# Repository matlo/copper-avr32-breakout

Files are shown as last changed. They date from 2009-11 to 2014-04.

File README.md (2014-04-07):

# AVR32 Breakout "Copper"

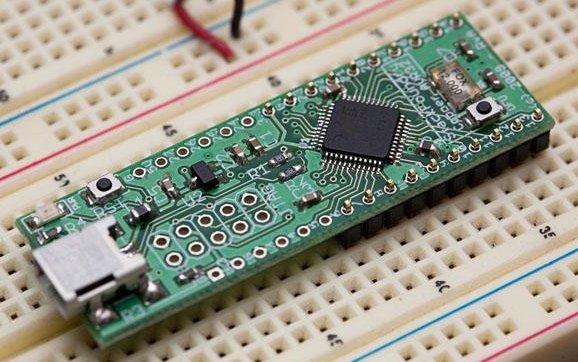
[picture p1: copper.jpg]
product


A breakout board for the AVR32 UC3B series of
processors. Specifically, the UC3B1256, a 48 pin part with 256KiB of
Flash (http://www.atmel.com/devices/AT32UC3B1256.aspx).

The year was 2009, and the Cortex-M3 was just a glimmer on some
product roadmaps. Yet Atmel delivered a 32-bit micro-controller which
was really efficient, had good performance, and was easy to use.

Modern designs should use a well-supported Cortex-M series part (M3,
M4, M0)

# Features

 * AVR 32 UC3B156
 * Mini-B USB connector
 * Breadboard-compatible pin pitch
 * All pins (except USB) broken out to the headers
 * JTAG connector
 * Reset button
 * Green LED :-)

# License

Creative Commons 3.0 Share-Alike Unported

# Design Status

This design was in larger (100-unit lots) production and was sold as a
pre-assembled kit.

## Boards available

A limited number of boards are available. Send an e-mail to
yann@stackfoundry.com with your mailing address. US postage is free,
International will be dealt with as it happens :-)

Boards will be populated with processors if they are available.

# Files available

The original design is available as Eagle 6.x (XML-based) design
files, in the eagle/ directory.

Gerber files from the Eagle board file are made available in the
gerber/ directory.

Schematic PDF is available in the root of this repository.

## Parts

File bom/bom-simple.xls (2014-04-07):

Qty | RefDeg | Manuf | Part# | Desc
1 | U1 | Atmel | AT32UC3B1256 | Microcontroller (MCU) 32-bit
2 | DFU,RST | Omrom | B3U-1000P | Tactile & Jog Switches Top Actuated w/o boss w/o ground
1 | U2 | Microchip | MCP1702 | Low Dropout (LDO) Regulators LDO w/ Low Quiescent
1 | Q1 | Fox | FQ5032B-12 | Crystals 12.0MHz 30ppm 0C +70C
2 | R1,R2 | Yageo | RC0603FR-0739RL | Resistor 0603 39ohm
1 | C4 | MuRata | GRM188F51A225ZE01D | Multilayer Ceramic Capacitors (MLCC) - SMD/SMT 0603 2.2uF 10volts Y5V +80-20%
1 | C1 | MuRata | GRM188F51A475ZE20D | Multilayer Ceramic Capacitors (MLCC) - SMD/SMT 0603 4.7uF 10volts Y5V +80-20%
1 | X2 | Hirose | UX60-MB-5ST | USB Mini B Conector
3 | C2,C5,C8,C3 | Panasonic | ECJ-1VB1C104K | CAP .1UF 16V CERAMIC X7R 0603
1 | R4 | Yageo | RC0603JR-07220RL | Resistors 0603 220 OHM 5%
2 | C7,C6 | MuRata | GRM1885C2A120JA01D | Multilayer Ceramic Capacitors (MLCC) - 0603 12pF or 16pF C0G/NPO
1 | L1 | Vishay | ILSB0805ERR10K | Common Mode Inductors .1uH 10%
1 | R3 | Yageo | RC0603JR-0747KL | Resistors 0603 47K OHM 5%
1 | PWR | Lumex | SML-LX1206GC-TR | LED 565NM WTR CLR GREEN 1206 SMD

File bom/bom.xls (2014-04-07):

Qty | RefDeg | Manuf | Part# | Desc | DigiKey Part# | Mouser Part#
1 | U3 | Atmel | AT32UC3B1256 | Microcontrollers (MCU) 32-bit |  | 556-AT32UC3B1256-AUT
2 |  | Omrom | B3U-1000P | Tactile & Jog Switches Top Actuated w/o boss w/o ground |  | 653-B3U-1000P
1 |  | Microchip | MCP1702 | Low Dropout (LDO) Regulators LDO w/ Low Quiescent |  | 579-MCP1702T3302E/CB
1 |  | Fox | FQ5032B-12 | Crystals 12.0MHz 30ppm 0C +70C |  | 559-FQ5032B-12
2 |  | Yageo | RC0603FR-0739RL | 0603 39ohm |  | 603-RC0603FR-0739RL
1 |  | MuRata | GRM188F51A225ZE01D | Multilayer Ceramic Capacitors (MLCC) - SMD/SMT 0603 2.2uF 10volts Y5V +80-20% |  | 81-GRM188F51A225ZE01
1 |  | MuRata | GRM188F51A475ZE20D | Multilayer Ceramic Capacitors (MLCC) - SMD/SMT 0603 4.7uF 10volts Y5V +80-20% |  | 81-GRM188F51A475ZE20
1 |  | FCI | 67997-420HLF | Headers 20 POS HEADER |  | 649-67997-420HLF | Optional
1 |  | Hirose | UX60-MB-5ST | USB Mini B |  | 798-ux60-mb-5st
3 |  | Panasonic | ECJ-1VB1C104K | CAP .1UF 16V CERAMIC X7R 0603 | PCC1762TR-ND
1 |  | Yageo | RC0603JR-07220RL | Thick Film Resistors SMD 220 OHM 5% |  | 603-RC0603JR-07220RL
2 |  | MuRata | GRM1885C2A120JA01D | Multilayer Ceramic Capacitors (MLCC) - SMD/SMT 0603 12pF 100volts C0G 5% |  | 81-GRM185C2A120JA01D
1 |  | Vishay | ILSB0805ERR10K | Common Mode Inductors .1uH 10% |  | 70-ILSB0805ERR10K
1 |  | Yageo | RC0603JR-0747KL | Thick Film Resistors SMD 47K OHM 5% |  | 603-RC0603JR-0747KL
1 | LED1 | Lumex | SML-LX1206GC-TR | LED 565NM WTR CLR GREEN 1206 SMD | 67-1357-1-ND
2 |  | FCI | 68000-216HLF | CONN HEADER 16POS .100 STR 15AU | 609-3260-ND |  | Optional

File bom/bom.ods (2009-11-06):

Qty | RefDeg | Manuf | Part# | Desc | DigiKey Part# | SFPN | Pricing
 |  |  |  |  |  |  | 1 | 10 | 25 | 100 | 1000 | Extended @ 100
1 | U3 | Atmel | AT32UC3B1256 | Microcontrollers (MCU) 32-bit | 556-AT32UC3B1256-AUT |  | 8.170000 | 8.060000 | 6.190000 | 5.700000 |  | 5.700000
2 |  | Omrom | B3U-1000P | Tactile & Jog Switches Top Actuated w/o boss w/o ground | 653-B3U-1000P |  | 0.770000 |  | 0.680000 | 0.580000 |  | 1.160000
1 |  | Microchip | MCP1702 | Low Dropout (LDO) Regulators LDO w/ Low Quiescent | 579-MCP1702T1802E/CB |  | 0.520000 | 0.480000 | 0.400000 | 0.360000 |  | 0.360000
1 |  | Fox | FQ5032B-12 | Crystals 12.0MHz 30ppm 0C +70C | 559-FQ5032B-12 |  | 1.070000 | 0.870000 | 0.780000 |  |  | 0.000000
2 |  | Yageo | RC0603FR-0739RL | 0603 39ohm | 603-RC0603FR-0739RL |  |  |  |  | 0.000100 |  | 0.000200
1 |  | MuRata | GRM188F51A225ZE01D | Multilayer Ceramic Capacitors (MLCC) - SMD/SMT 0603 2.2uF 10volts Y5V +80-20% | 81-GRM188F51A225ZE01 |  |  |  |  | 0.150000 |  | 0.150000
1 |  | MuRata | GRM188F51A475ZE20D | Multilayer Ceramic Capacitors (MLCC) - SMD/SMT 0603 4.7uF 10volts Y5V +80-20% | 81-GRM188F51A475ZE20 |  | 0.480000 |  |  | 0.150000 |  | 0.150000
1 |  | FCI | 67997-420HLF | Headers 20 POS HEADER | 649-67997-420HLF |  |  |  |  | 0.440000 |  | 0.440000
1 |  | Hirose | UX60-MB-5ST | USB Mini B | 798-ux60-mb-5st |  | 1.180000 |  |  | 0.700000 |  | 0.700000
 |  |  |  |  |  |  |  |  |  |  |  | 0.000000
 |  |  |  |  |  |  |  |  |  |  |  | 0.000000
 |  |  |  |  |  |  |  |  |  |  |  | 0.000000
 |  |  |  |  |  |  |  |  |  |  |  | 0.000000
 |  |  |  |  |  |  |  |  |  |  |  | 0.000000
1 | LED1,LED2 | Lumex | SML-LX1206GC-TR | LED 565NM WTR CLR GREEN 1206 SMD | 67-1357-1-ND | SFCLED-GRN-1206 | 0.160000 | 0.140000 | 0.140000 | 0.120000 |  | 0.120000
 |  |  |  |  |  |  |  |  |  |  |  |  | UpFront
 |  |  |  |  |  |  |  |  |  |  | Comp Total | 8.78
 |  |  |  |  |  |  |  |  |  |  | Box | 3
 |  |  |  |  |  |  |  |  |  |  | PCB | 3
 |  |  |  |  |  |  |  |  |  |  | Subtotal | 14.78 | 147.8
 |  |  |  |  |  |  |  |  |  |  | Margin | 29.56

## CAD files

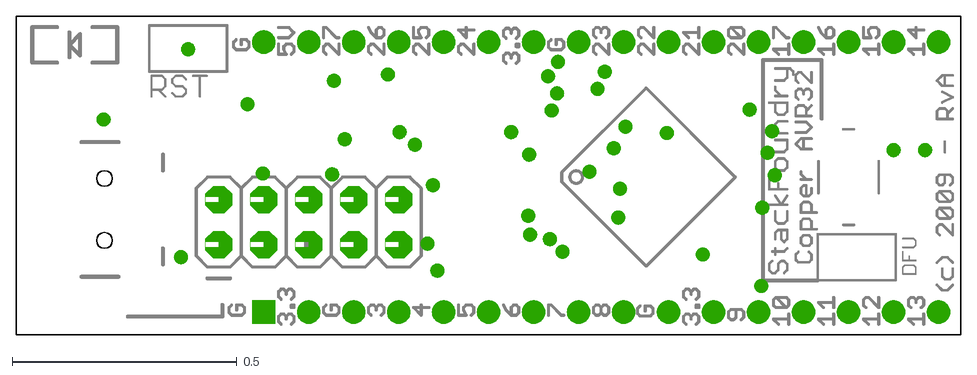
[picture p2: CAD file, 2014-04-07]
gerber/copper.dxf
2.10 x 0.707

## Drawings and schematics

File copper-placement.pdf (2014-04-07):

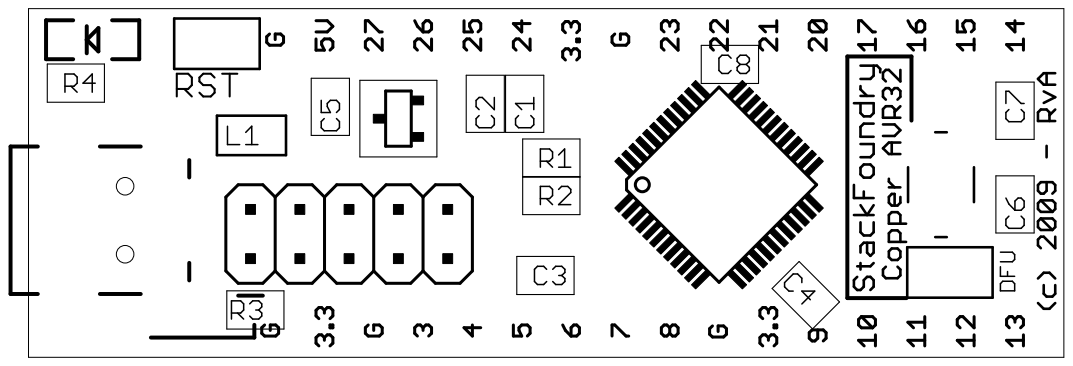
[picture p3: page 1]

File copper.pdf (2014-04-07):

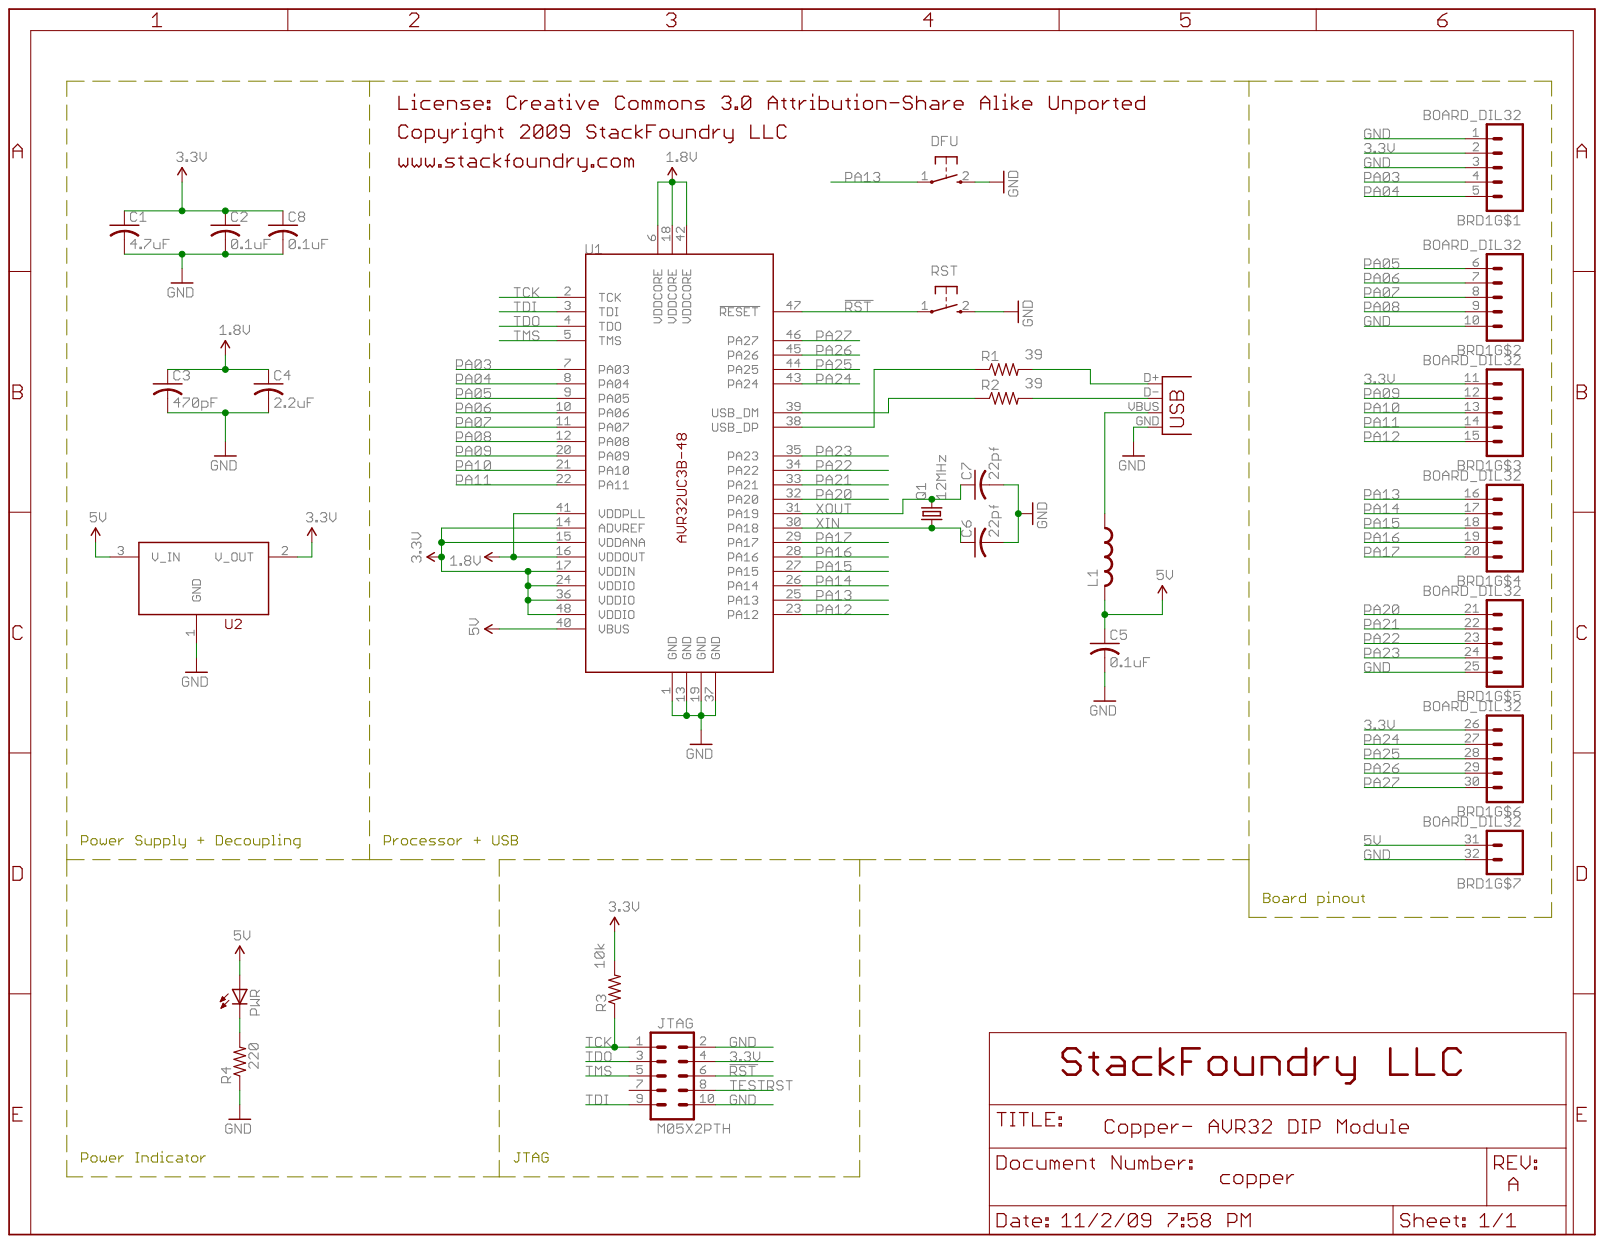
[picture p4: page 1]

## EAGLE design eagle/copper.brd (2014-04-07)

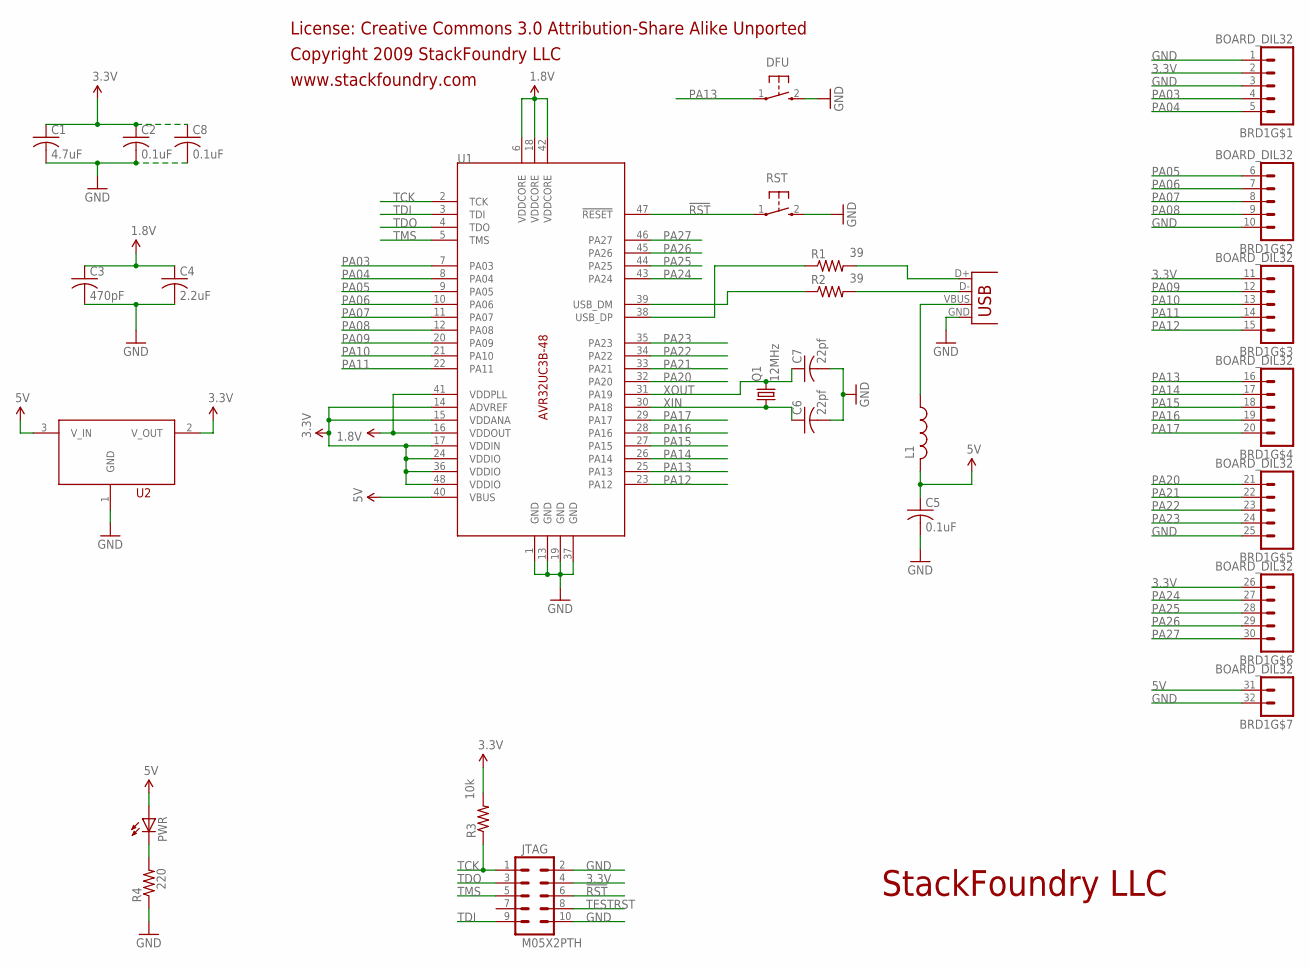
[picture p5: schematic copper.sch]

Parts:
BRD1: BOARD_DIL32; DIL32-NOSILK
C1: 4.7uF; C0603
C2, C5, C8: 0.1uF; C0603
C3: 470pF; C0603
C4: 2.2uF; C0603
C6, C7: 22pf; C0603
DFU: TAC_SWITCH_2PB3U; OMROM_B3U
JTAG: M05X2PTH; AVR_ICSP
L1: L-USL0805; L0805
PWR: LED1206; LED-1206
Q1: 12MHz; CRYSTAL-SMD-5X3.2
R1, R2: 39; R0603
R3: 10k; R0603
R4: 220; R0603
RST: TAC_SWITCH_2PB3U; OMROM_B3U
U1: AVR32UC3B-48TQFP; TQFP48
U2: MCP1700; SOT23
X2: USBSMD; USB-MINIB

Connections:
1.8V: C3.1, C4.1, U1.6 (VDDCORE), U1.16 (VDDOUT), U1.18 (VDDCORE), U1.41 (VDDPLL), U1.42 (VDDCORE)
3.3V: BRD1.2, BRD1.11 (1), BRD1.26 (1), C1.1, C2.1, C8.1, JTAG.4, R3.2, U1.14 (ADVREF), U1.15 (VDDANA), U1.17 (VDDIN), U1.24 (VDDIO), U1.36 (VDDIO), U1.48 (VDDIO), U2.2 (V_OUT)
5V: BRD1.31 (1), C5.1, L1.2, PWR.A, U1.40 (VBUS), U2.3 (V_IN)
!RST: JTAG.6, RST.1, U1.47 (!RESET)
GND: BRD1.1, BRD1.3, BRD1.10 (5), BRD1.25 (5), BRD1.32 (2), C1.2, C2.2, C3.2, C4.2, C5.2, C6.2, C7.2, C8.2, DFU.2 (3), JTAG.2, JTAG.10, R4.1, RST.2 (3), U1.1 (GND), U1.13 (GND), U1.19 (GND), U1.37 (GND), U2.1 (GND), X2.GND
unnamed: R1.1, U1.38 (USB_DP)
unnamed: R2.1, U1.39 (USB_DM)
unnamed: L1.1, X2.VBUS
unnamed: R1.2, X2.D+
unnamed: R2.2, X2.D-
unnamed: PWR.C, R4.2
PA03: BRD1.4, U1.7 (PA03)
PA04: BRD1.5, U1.8 (PA04)
PA05: BRD1.6 (1), U1.9 (PA05)
PA06: BRD1.7 (2), U1.10 (PA06)
PA07: BRD1.8 (3), U1.11 (PA07)
PA08: BRD1.9 (4), U1.12 (PA08)
PA09: BRD1.12 (2), U1.20 (PA09)
PA10: BRD1.13 (3), U1.21 (PA10)
PA11: BRD1.14 (4), U1.22 (PA11)
PA12: BRD1.15 (5), U1.23 (PA12)
PA13: BRD1.16 (1), DFU.1, U1.25 (PA13)
PA14: BRD1.17 (2), U1.26 (PA14)
PA15: BRD1.18 (3), U1.27 (PA15)
PA16: BRD1.19 (4), U1.28 (PA16)
PA17: BRD1.20 (5), U1.29 (PA17)
PA20: BRD1.21 (1), U1.32 (PA20)
PA21: BRD1.22 (2), U1.33 (PA21)
PA22: BRD1.23 (3), U1.34 (PA22)
PA23: BRD1.24 (4), U1.35 (PA23)
PA24: BRD1.27 (2), U1.43 (PA24)
PA25: BRD1.28 (3), U1.44 (PA25)
PA26: BRD1.29 (4), U1.45 (PA26)
PA27: BRD1.30 (5), U1.46 (PA27)
TCK: JTAG.1, R3.1, U1.2 (TCK)
TDI: JTAG.9, U1.3 (TDI)
TDO: JTAG.3, U1.4 (TDO)
TESTRST: JTAG.8
TMS: JTAG.5, U1.5 (TMS)
XIN: C6.1, Q1.1, U1.30 (PA18)
XOUT: C7.1, Q1.3 (2), U1.31 (PA19)

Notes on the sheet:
License: Creative Commons 3.0 Attribution-Share Alike Unported
Copyright 2009 StackFoundry LLC
www.stackfoundry.com
StackFoundry LLC

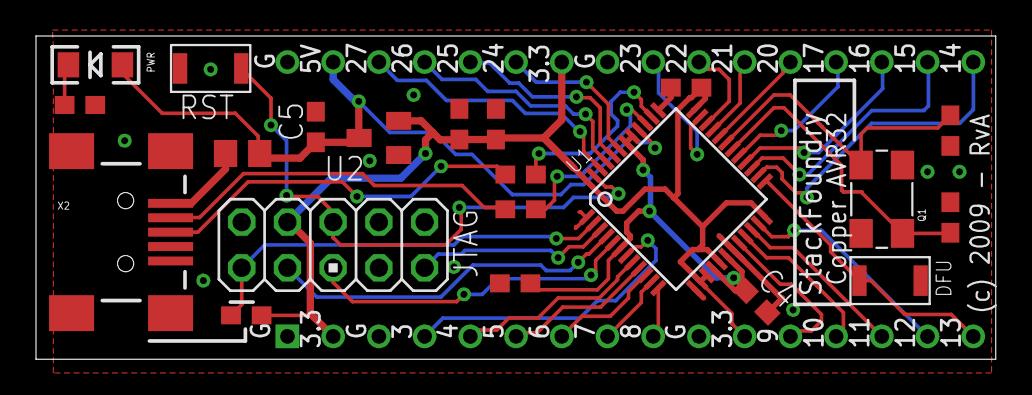
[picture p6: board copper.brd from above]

Board: 2 copper layers, 53.3 x 18.0 mm, 22 parts (0 on the bottom side), 40 nets.

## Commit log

2009-10-26 Copper schematic
    [copper.brd, copper.sch]
2009-10-26 Fix crystal
    [copper.brd, copper.sch]
2009-10-26 Gerber data
    [copper.brd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]
2014-04-07 Re-arrange files
    [bom-simple.xls, bom.ods, bom.xls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]
2014-04-07 Add artwork
    [copper.brd]

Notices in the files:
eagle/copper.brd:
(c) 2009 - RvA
